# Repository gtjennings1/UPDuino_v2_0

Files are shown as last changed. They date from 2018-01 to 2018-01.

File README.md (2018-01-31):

# UPDuino_v2_0
UPDuino v2.0 - PCB Design Files, Designs, Documentation

UPDuino v2.0 is a small, low cost FPGA board.  
It is the same board as UPDuino v1.0, but v2.0 has a built-in USB programmer
(Similar to Arduino Pro Mini vs Arduino Nano microcontroller boards respectively).

Gnarly Grey UPDuino v2.0 Board Features

    Lattice UltraPlus FPGA
        5.3K LUTs, 1Mb SPRAM, 120Kb DPRAM, 8 Multipliers
        
    FTDI FT232H USB to SPI Device
    
    34 GPIO on 0.1” headers
    
    SPI Flash, RGB LED, 3.3V and 1.2V Regulators
    
    Open source schematic and layout using free Eagle PCB design tools
        Download Schematic & Layout
        Schematic PDF
        Programming Instructions
        RGB LED Example Project

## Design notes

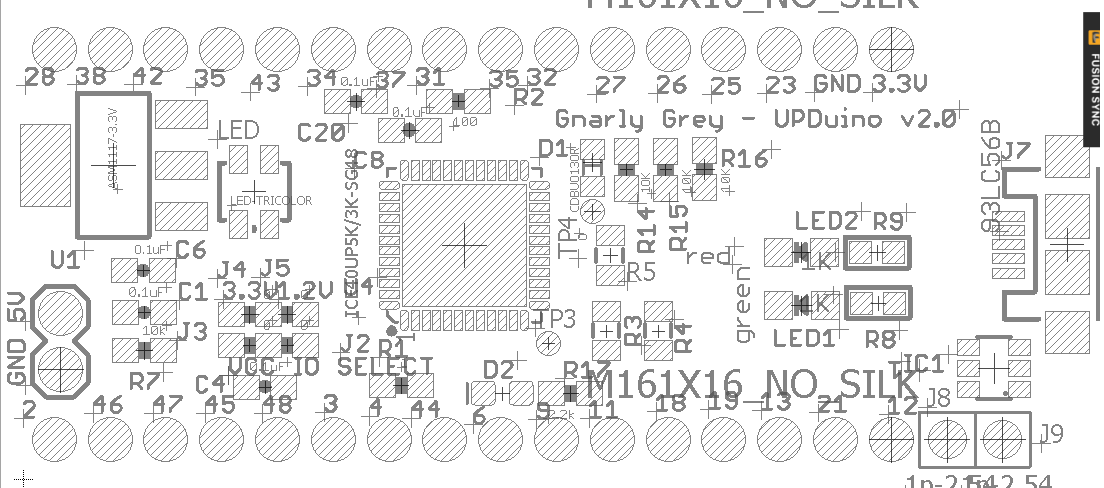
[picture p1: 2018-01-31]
PCB/top_orientation.png

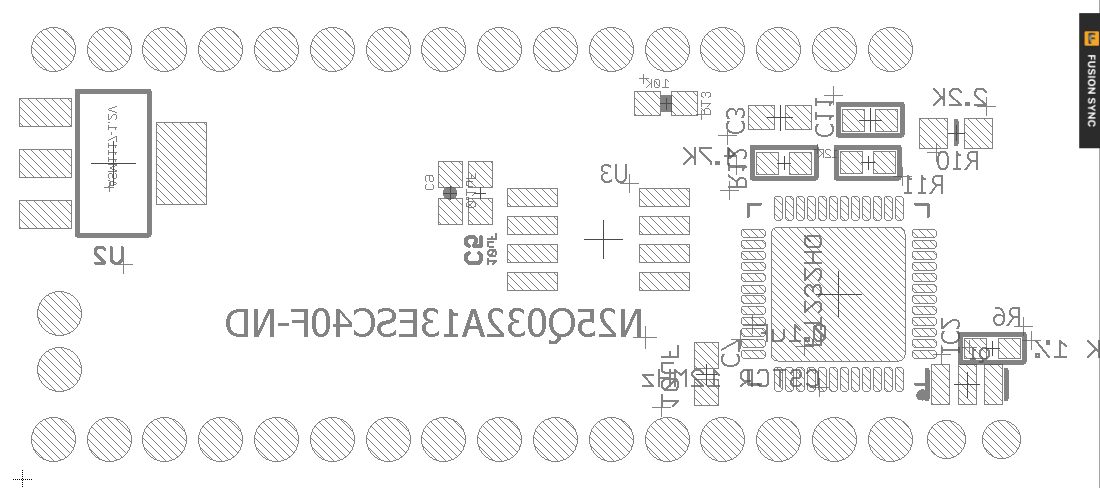
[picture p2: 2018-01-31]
PCB/bot_orientation.png

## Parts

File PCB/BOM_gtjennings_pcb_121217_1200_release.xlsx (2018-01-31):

EXAMPLE BILL OF MATERIALS (BOM)
Place your mouse over the red comment markers in the top right corner of the cells in the row below to see more info on the data in that column
1 | 2 | 3 | 4 | 5 | 6 | 7 | 8 | 9 | 10 | 11
Sequential Item Nos | Consolidated quantity of each Part No | Component ID's separated by Commas | Confirmation Yes or No Parts are fitted this Build (Note 1) | Full Description of Part e.g. for capacitor include value, tolerance and type or Dielectric | Value or Type No | Case Style | Supplier or Manufacturer (Note 2) | Supplier Stock No or Manufacturer's Part No (Note 2) | Side of Board Mounted | PTH or SMT
Item | Qty | Reference | Fit | Part Description | Value | Package | Supplier | Supplier Ref | Side | Mount Type
1 | 6 | C1,C3,C6,C8,C11,C20,C9 | Y | Capacitors | 0.1uF | 0603-CAP |  |  |  | S
2 | 1 | C7,C5 | y | Capacitors | 10uF | 0603-CAP
3 | 1 | D1 | Y | Diode | CDBU0130R | SOD523 |  |  |  | S
4 | 1 | D2 | Y | GREEN LED_0603 | APT1608SGC (https://www.digikey.com/product-detail/en/kingbright/APT1608SGC/754-1121-1-ND/1747838) | 0603_LED
5 | 0 | J6,JP5,JP6 | N | Connectors | DNI | 0603-RES |  |  |  | P
6 | 2 | J3, J4 | Y | Resistors | 0 | 0603-RES
7 | 0 | J2, J5 | N | Resistors | DNI | 0603-RES |  |  |  | S
8 | 1 | J7 | Y | USB connector | USB-MicroB | 10118192-0001LF (https://www.digikey.com/product-detail/en/amphenol-fci/10118192-0001LF/609-4613-1-ND/2785378) |  | 10118192-0001LF (https://www.digikey.com/product-detail/en/amphenol-fci/10118192-0001LF/609-4613-1-ND/2785378)
9 | 1 | LED | Y | LED | LED-TRICOLOR | LED-TRICOLOR-SMD |  | CLV1L-FKB-CHMMQEHBB7673673CT-ND | T | S
10 | 1 | R1 | Y | Resistors | 1 | 0603-RES |  |  |  | S
11 | 2 | R2,R17 | Y | Resistors | 100 | 0603-RES |  |  |  | S
12 | 1 | R3 | Y | Resistors | 0 | 0603-RES |  |  |  | P
13 | 2 | R4,R5 | Y | Resistors | 0 | 0805-RES |  |  |  | P
14 | 1 | R6 | Y | Resistors | 12k 1% | 0603-RES
15 | 5 | R7,R13,R14,R15,R16 | Y | Resistors | 10k | 0603-RES |  |  |  | S
16 | 2 | R8,R9 | Y | Resistors | 1k | 0603-RES
17 | 1 | R10 | Y | Resistors | 2.2k | 0603-RES
18 | 1 | R11 | Y | Resistors | 4.7k | 0603-RES
19 | 1 | R12 | Y | Resistors | 12k | 0603-RES
20 | 1 | U1 | Y | PowerIC | ASM1117-3.3 | SOT223 |  | ASM1117-3.3 | T | S
21 | 1 | U2 | Y | PowerIC | ASM1117-1.2 | SOT223 |  | ASM1117-1.2 | B | S
22 | 1 | U3 | Y | 25Q32 | 25Q32 | SO8 | Winbond Electronics (https://www.digikey.com/en/supplier-centers/w/winbond-electronics) | 25Q32 | B | S
23 | 1 | U4 | Y | ICE40UP5K-3K-SG48 | ICE40UP5K/3K-SG48 | ICE40UP5K/3K-SG48 | Lattice Semiconductor | ICE40UP5K/3K-SG48 | T | S
24 | 1 | IC1 | Y | Memory IC | 93LC56B | SOT23-6
25 | 1 | IC2 | Y | FT232HQ IC | FT232HQ | QFN48_8MM
26 | 1 | Q1 | Y | Resonator_smd | CSTCR 12MHz | CSTCE12M0G55-R0 (https://www.digikey.com/product-detail/en/murata-electronics-north-america/CSTCE12M0G55-R0/490-1197-1-ND/584634)
 | 37

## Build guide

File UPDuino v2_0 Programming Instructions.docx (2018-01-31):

UPDuino v2.0 Device Programming

Hardware Needed:

- Gnarly Grey UPDuino v2.0 Board
  - http://gnarlygrey.atspace.cc/development-platform.html#upduino_v2

Software Needed:

- Lattice Diamond Programmer Standalone (v3.9 x64 used for programming instructions)
  - http://www.latticesemi.com/en/Products/DesignSoftwareAndIP/ProgrammingAndConfigurationSw/Programmer.aspx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
- Lattice iCECube2 Software (
  - http://www.latticesemi.com/Products/DesignSoftwareAndIP/FPGAandLDS/iCEcube2.aspx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

FPGA Projects Needed:

- UPDuino Blinky LED Design
  - http://www.gnarlygrey.com/downloads/RGB_LED_BLINK_20170606.tar

Programming (SPI Flash):

1. Plug UPDuino v2.0 in to your PC using the micro USB port on the board
2. Open Lattice Diamond Programmer
3. Click ‘Detect Cable’ then ‘OK’
4. After scanning select ‘Generic JTAG Device’ and ‘Select iCE40 UltraPlus’
5. Under ‘Device’ click iCE40UP3K and change it to iCE40UP5K
6. Under ‘Operation’ double click ‘Fast Program’ and change ‘Access Mode:’ to ‘SPI Flash Programming’
7. Select your *.hex programming file under ‘Programming file’.
8. Configure the following ‘SPI Flash Options’
  a. Numonyx
  b. SPI-N25Q032
  c. 8-pin VDFPN8
9. Click ‘Load from File’ under ‘SPI Programming’ to get load size
10. Click ‘Design’→’Program’

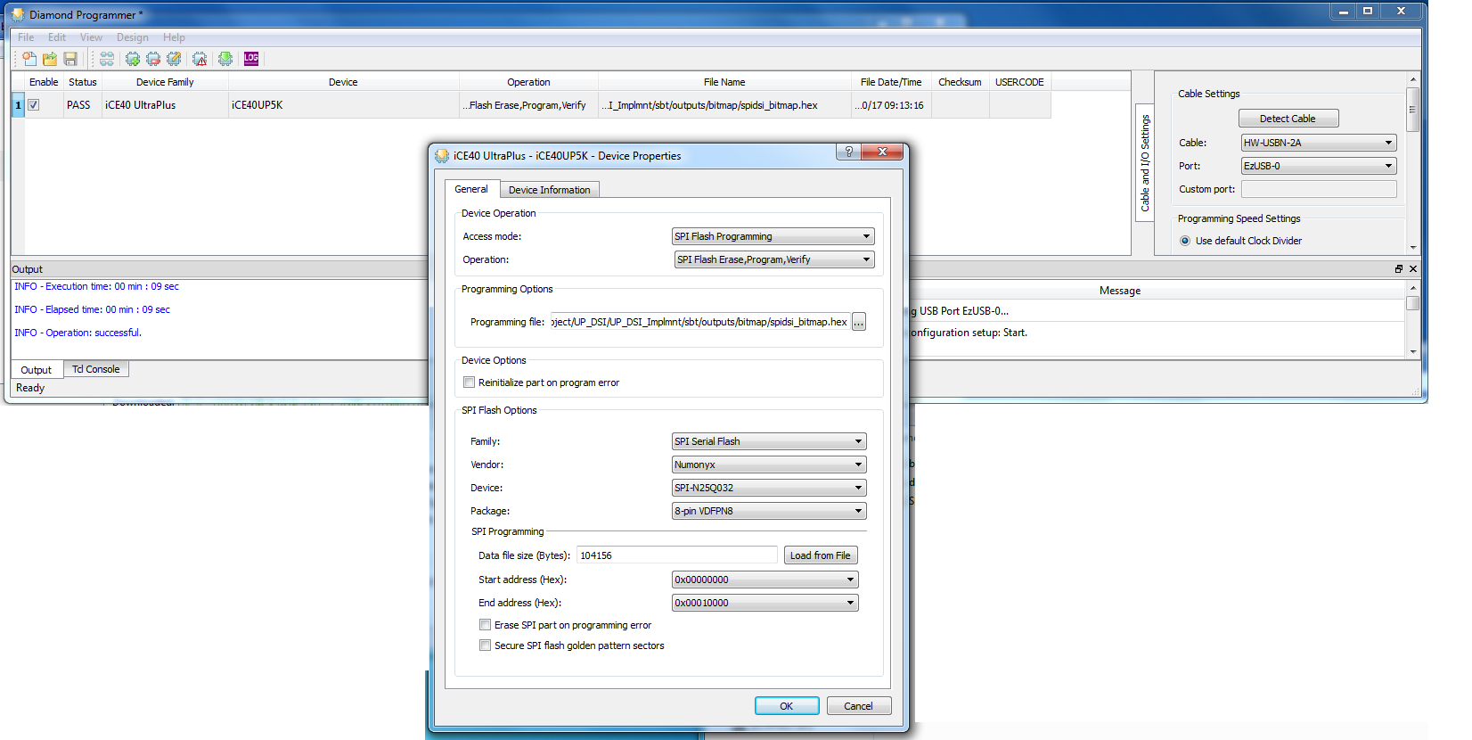
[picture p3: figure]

Project Synthesis (Compiling) and bitstream (Firmware) generation:

1. Unzip RGB_LED_BLINK_20170606.zip
2. Open Lattice iCECube2 Software
3. Double click ‘Open Project’
4. Navigate to *\RGB_LED_BLINK_20170606\rgb\rgb_sbt.project and ‘Open’
5. Double click ‘Run Synplify Pro Synthesis’
6. Right click on ‘Run P&R’ and left click ‘Run Bitmap’
  a. Note – this will run all remaining synthesis steps including place, route and bitmap generation.
  b. Generated bitstream will be loaded in the *\rgb\rgb_Implmnt\sbt\outputs\bitmap folder

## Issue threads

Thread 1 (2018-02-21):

12Mhz clock source from FTDI as external clock for FPGA PLL?

fanoush, 2018-02-21:
Looks like the OSC_OUT from the FTDI goes to J9. Is it supposed to be connected back to FPGA as external clock source for the PLL to get stable clock? Could you perhaps document it  a bit (possibly also with a few verilog lines) how to do it if it is indeed supposed to be used like that? Many thanks.

olofk, 2018-12-03:
I would very much want to know this too. The HFOSC/LFOSC specs states a +-10% accuracy, which is pretty much, and might be problematic even with a simple thing as a UART

fanoush, 2019-03-26:
Just answering myself. I finally tried and it seems to work. I've seen J8 somehow being connected on FPGA [101 board](https://hackaday.io/project/158275-fpga-101-workshop-badge) and examples took 12MHz clock from [pin 35](https://github.com/mmicko/fpga101-workshop/blob/master/projects/galaksija/pinout.pcf).

 I did not find pdf schematics of the board  howeverI connected J8 to pin 35 by wire and modified blinker example and indeed it worked and blinked much slower than with internal 48MHz. I guess pin 35 is chosen as it is [global pin](https://github.com/osresearch/up5k/blob/master/images/pinout.jpg) so the clock can be directly routed to any part of fpga (?)

I also tried to connect it to nearest pin 12 and used is as source for pll and derive 48MHz clock from it and it worked too and blinker example blinked again as with internal 48MHz clock. For that I used output of 'icepll -o 48 -m -f pll.v' command and used pin 12 as clock_in

So I am not sure if this is safe and whether there is some additional setting possible on the input pin so it would not e.g. put extra load on osc_out but it seems to work as is :-)

fanoush, 2019-03-26:
> I did not find pdf schematics

OK I found https://github.com/mmicko/workshop_badge/tree/master/workshop-gerber and uploaded badge.zip to http://www.gerber-viewer.com/ and it seems J8 simply goes to pin 35 so I guess that's it.

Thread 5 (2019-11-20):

Cannot "Detect Cable" in diamond programmer

mattroos, 2019-11-20:
@gtjennings1, I'm using Ubuntu 16.04. I downloaded the Diamond programmer standalone (version 3.11x64 is the only one I've found available on the Lattice website), converted it from RPM to DEB file, and installed it using dpkg.

When I launch the programmer I get a GUI with three radio buttons. The one labeled "Create a new project from a JTAG scan" has below it a "Detect Cable" button, and drop-down lists for "Cable" and "Port". All of this is grayed out, however. The only two radio buttons that are available for selection are "Create a new blank project" and "Open an existing programmer project".

Any advice on how to fix this?

mattroos, 2019-11-21:
Additionally, I tried the suggestions found [here](https://ycnrg.org/lattice-diamond-on-ubuntu-16-04/), to no avail. Also, if I chose the "Create a new blank project" radio button, a new project is created and the GUI changes to one that looks like of the image in the page linked above, with an enabled "Detect Cable" button. But no FTDI USB host chip is detected.

mattroos, 2019-12-18:
I beat my head on this for a while to no avail. I also tried installing Fedora (a Red Hat derivative) and installed the Diamond programmer from the RPM, then again follow suggestions from the link above (which are similar to the installation instructions in the Lattice manual). All for naught.

I've given up, installed Windows 10 instead, and can now successfully complete the tasks in the [programming instructions](https://github.com/gtjennings1/UPDuino_v2_0/blob/master/UPDuino%20v2_0%20Programming%20Instructions.docx).

Closed 2019-12-18.

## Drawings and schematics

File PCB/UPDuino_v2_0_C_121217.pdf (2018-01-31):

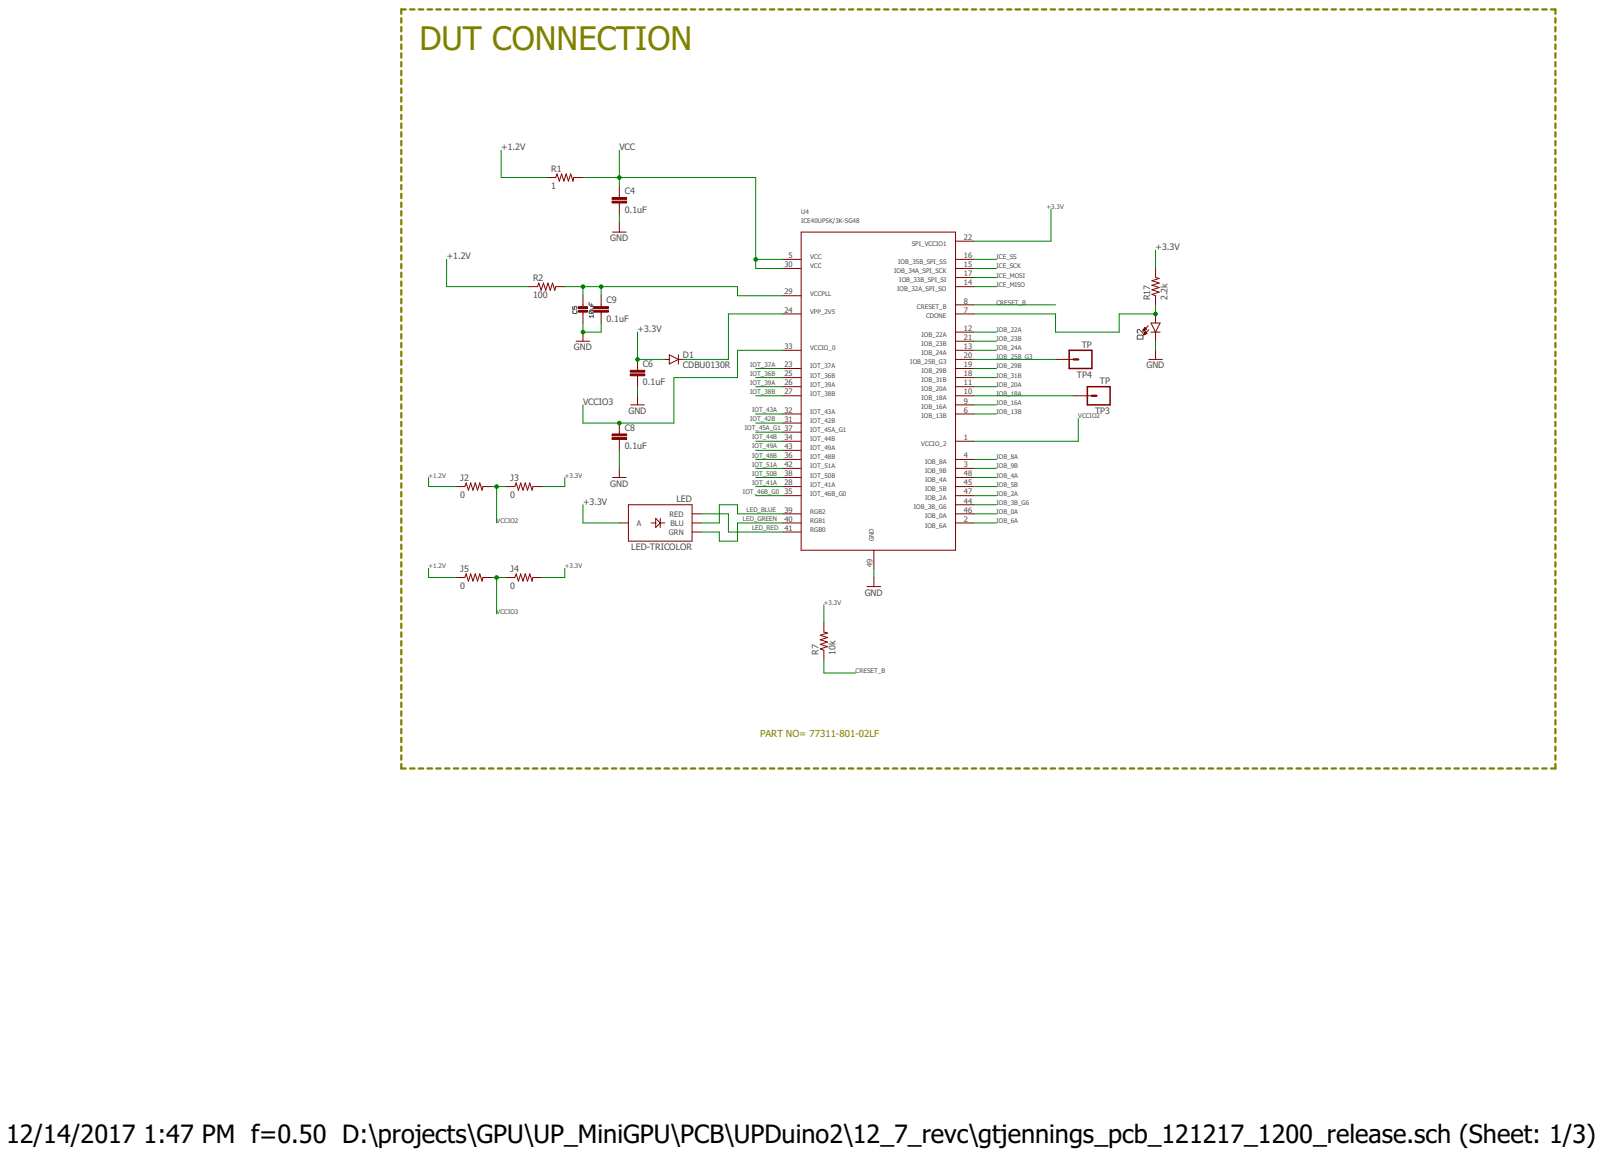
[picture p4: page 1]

12/14/2017 1:47 PM f=0.50 D:\projects\GPU\UP_MiniGPU\PCB\UPDuino2\12_7_revc\gtjennings_pcb_121217_1200_release.sch (Sheet: 1/3)

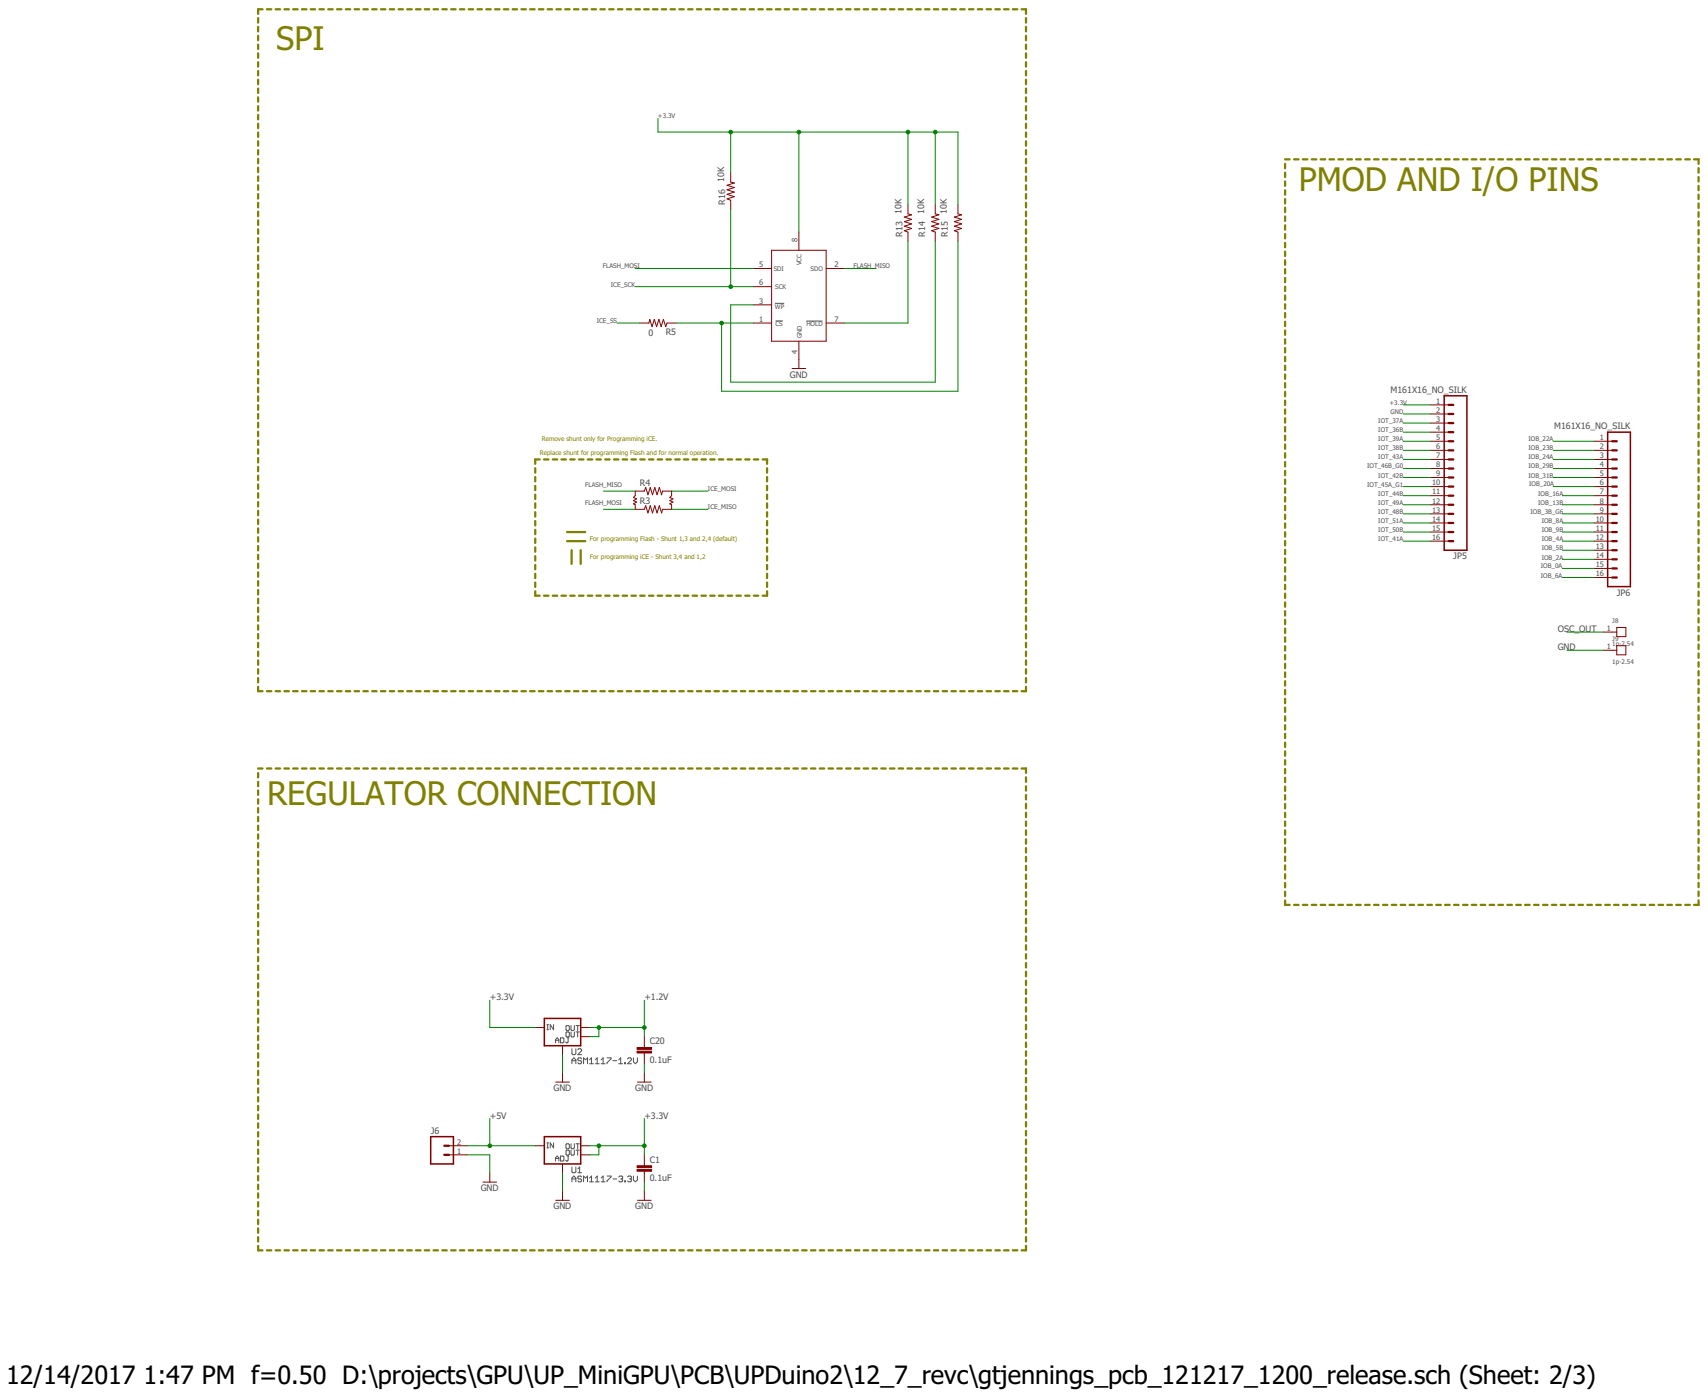
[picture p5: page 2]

Remove shunt only for Programming iCE. Replace shunt for programming Flash and for normal operation.

For programming Flash - Shunt 1,3 and 2,4 (default) For programming iCE - Shunt 3,4 and 1,2

12/14/2017 1:47 PM f=0.50 D:\projects\GPU\UP_MiniGPU\PCB\UPDuino2\12_7_revc\gtjennings_pcb_121217_1200_release.sch (Sheet: 2/3)

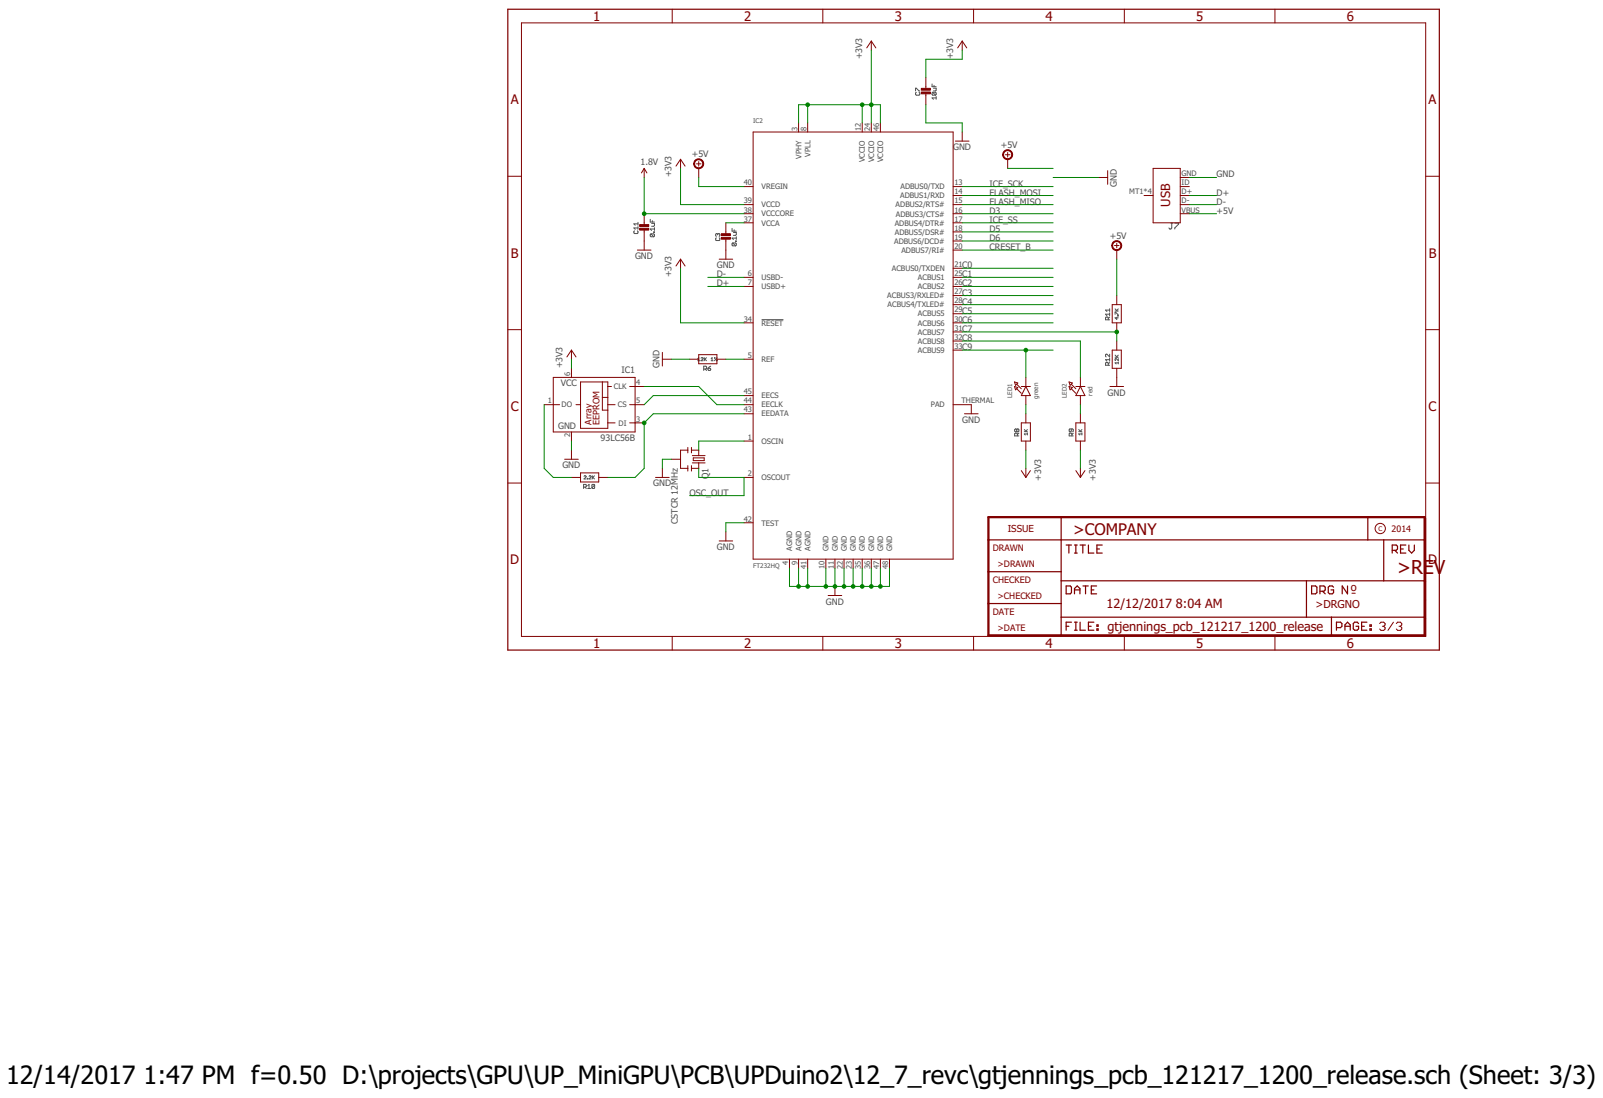
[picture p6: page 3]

12/14/2017 1:47 PM f=0.50 D:\projects\GPU\UP_MiniGPU\PCB\UPDuino2\12_7_revc\gtjennings_pcb_121217_1200_release.sch (Sheet: 3/3)

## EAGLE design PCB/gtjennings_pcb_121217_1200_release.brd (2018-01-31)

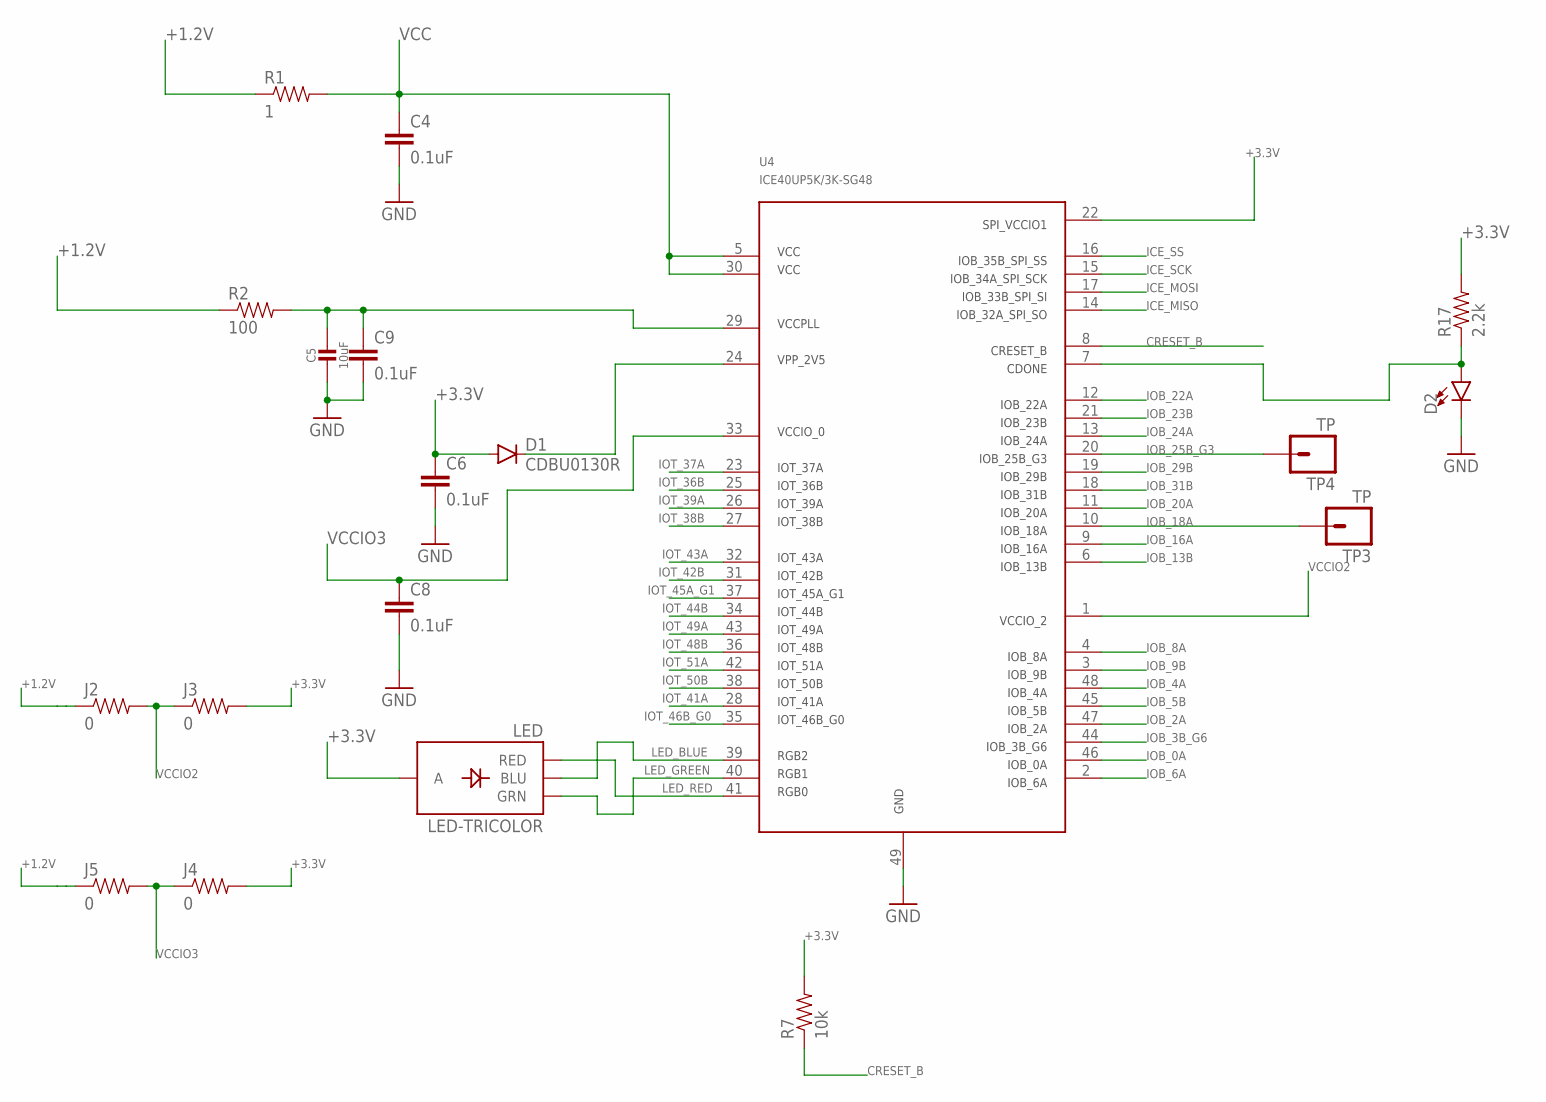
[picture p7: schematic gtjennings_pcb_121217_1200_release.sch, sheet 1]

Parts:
C4, C6, C8, C9: 0.1uF; 0603-CAP
C5: 10uF; 0603-NO
D1: CDBU0130R; SOD523
D2: LED0603; LED-0603
J2, J3, J4, J5: 0; 0603-RES
LED: LED-TRICOLOR; LED-TRICOLOR-SMD
R1: 1; 0603-RES
R2: 100; 0603-RES
R7: 10k; 0603-RES
R17: 2.2k; 0603-RES
TP3, TP4: TP
U4: ICE40UP5K/3K-SG48

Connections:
+1.2V: J2.1, J5.1, R1.1, R2.1; also elsewhere on the board
+3.3V: C6.1, D1.A, J3.2, J4.2, LED.A, R7.2, R17.2, U4.22; also elsewhere on the board
CRESET_B: R7.1, U4.8; also elsewhere on the board
GND: C4.2, C5.2, C6.2, C8.2, C9.2, D2.C, U4.49; also elsewhere on the board
ICE_MISO: U4.14; also elsewhere on the board
ICE_MOSI: U4.17; also elsewhere on the board
ICE_SCK: U4.15; also elsewhere on the board
ICE_SS: U4.16; also elsewhere on the board
IOB_0A: U4.46; also elsewhere on the board
IOB_2A: U4.47; also elsewhere on the board
IOB_3B_G6: U4.44; also elsewhere on the board
IOB_4A: U4.48; also elsewhere on the board
IOB_5B: U4.45; also elsewhere on the board
IOB_6A: U4.2; also elsewhere on the board
IOB_8A: U4.4; also elsewhere on the board
IOB_9B: U4.3; also elsewhere on the board
IOB_13B: U4.6; also elsewhere on the board
IOB_16A: U4.9; also elsewhere on the board
IOB_18A: TP3.1, U4.10
IOB_20A: U4.11; also elsewhere on the board
IOB_22A: U4.12; also elsewhere on the board
IOB_23B: U4.21; also elsewhere on the board
IOB_24A: U4.13; also elsewhere on the board
IOB_25B_G3: TP4.1, U4.20
IOB_29B: U4.19; also elsewhere on the board
IOB_31B: U4.18; also elsewhere on the board
IOT_36B: U4.25; also elsewhere on the board
IOT_37A: U4.23; also elsewhere on the board
IOT_38B: U4.27; also elsewhere on the board
IOT_39A: U4.26; also elsewhere on the board
IOT_41A: U4.28; also elsewhere on the board
IOT_42B: U4.31; also elsewhere on the board
IOT_43A: U4.32; also elsewhere on the board
IOT_44B: U4.34; also elsewhere on the board
IOT_45A_G1: U4.37; also elsewhere on the board
IOT_46B_G0: U4.35; also elsewhere on the board
IOT_48B: U4.36; also elsewhere on the board
IOT_49A: U4.43; also elsewhere on the board
IOT_50B: U4.38; also elsewhere on the board
IOT_51A: U4.42; also elsewhere on the board
LED_BLUE: LED.B (BLU), U4.39
LED_GREEN: LED.G (GRN), U4.40
LED_RED: LED.R (RED), U4.41
unnamed: C5.1, C9.1, R2.2, U4.29
unnamed: D1.C, U4.24
unnamed: D2.A, R17.1, U4.7
VCC: C4.1, R1.2, U4.5, U4.30
VCCIO2: J2.2, J3.1, U4.1
VCCIO3: C8.1, J4.1, J5.2, U4.33

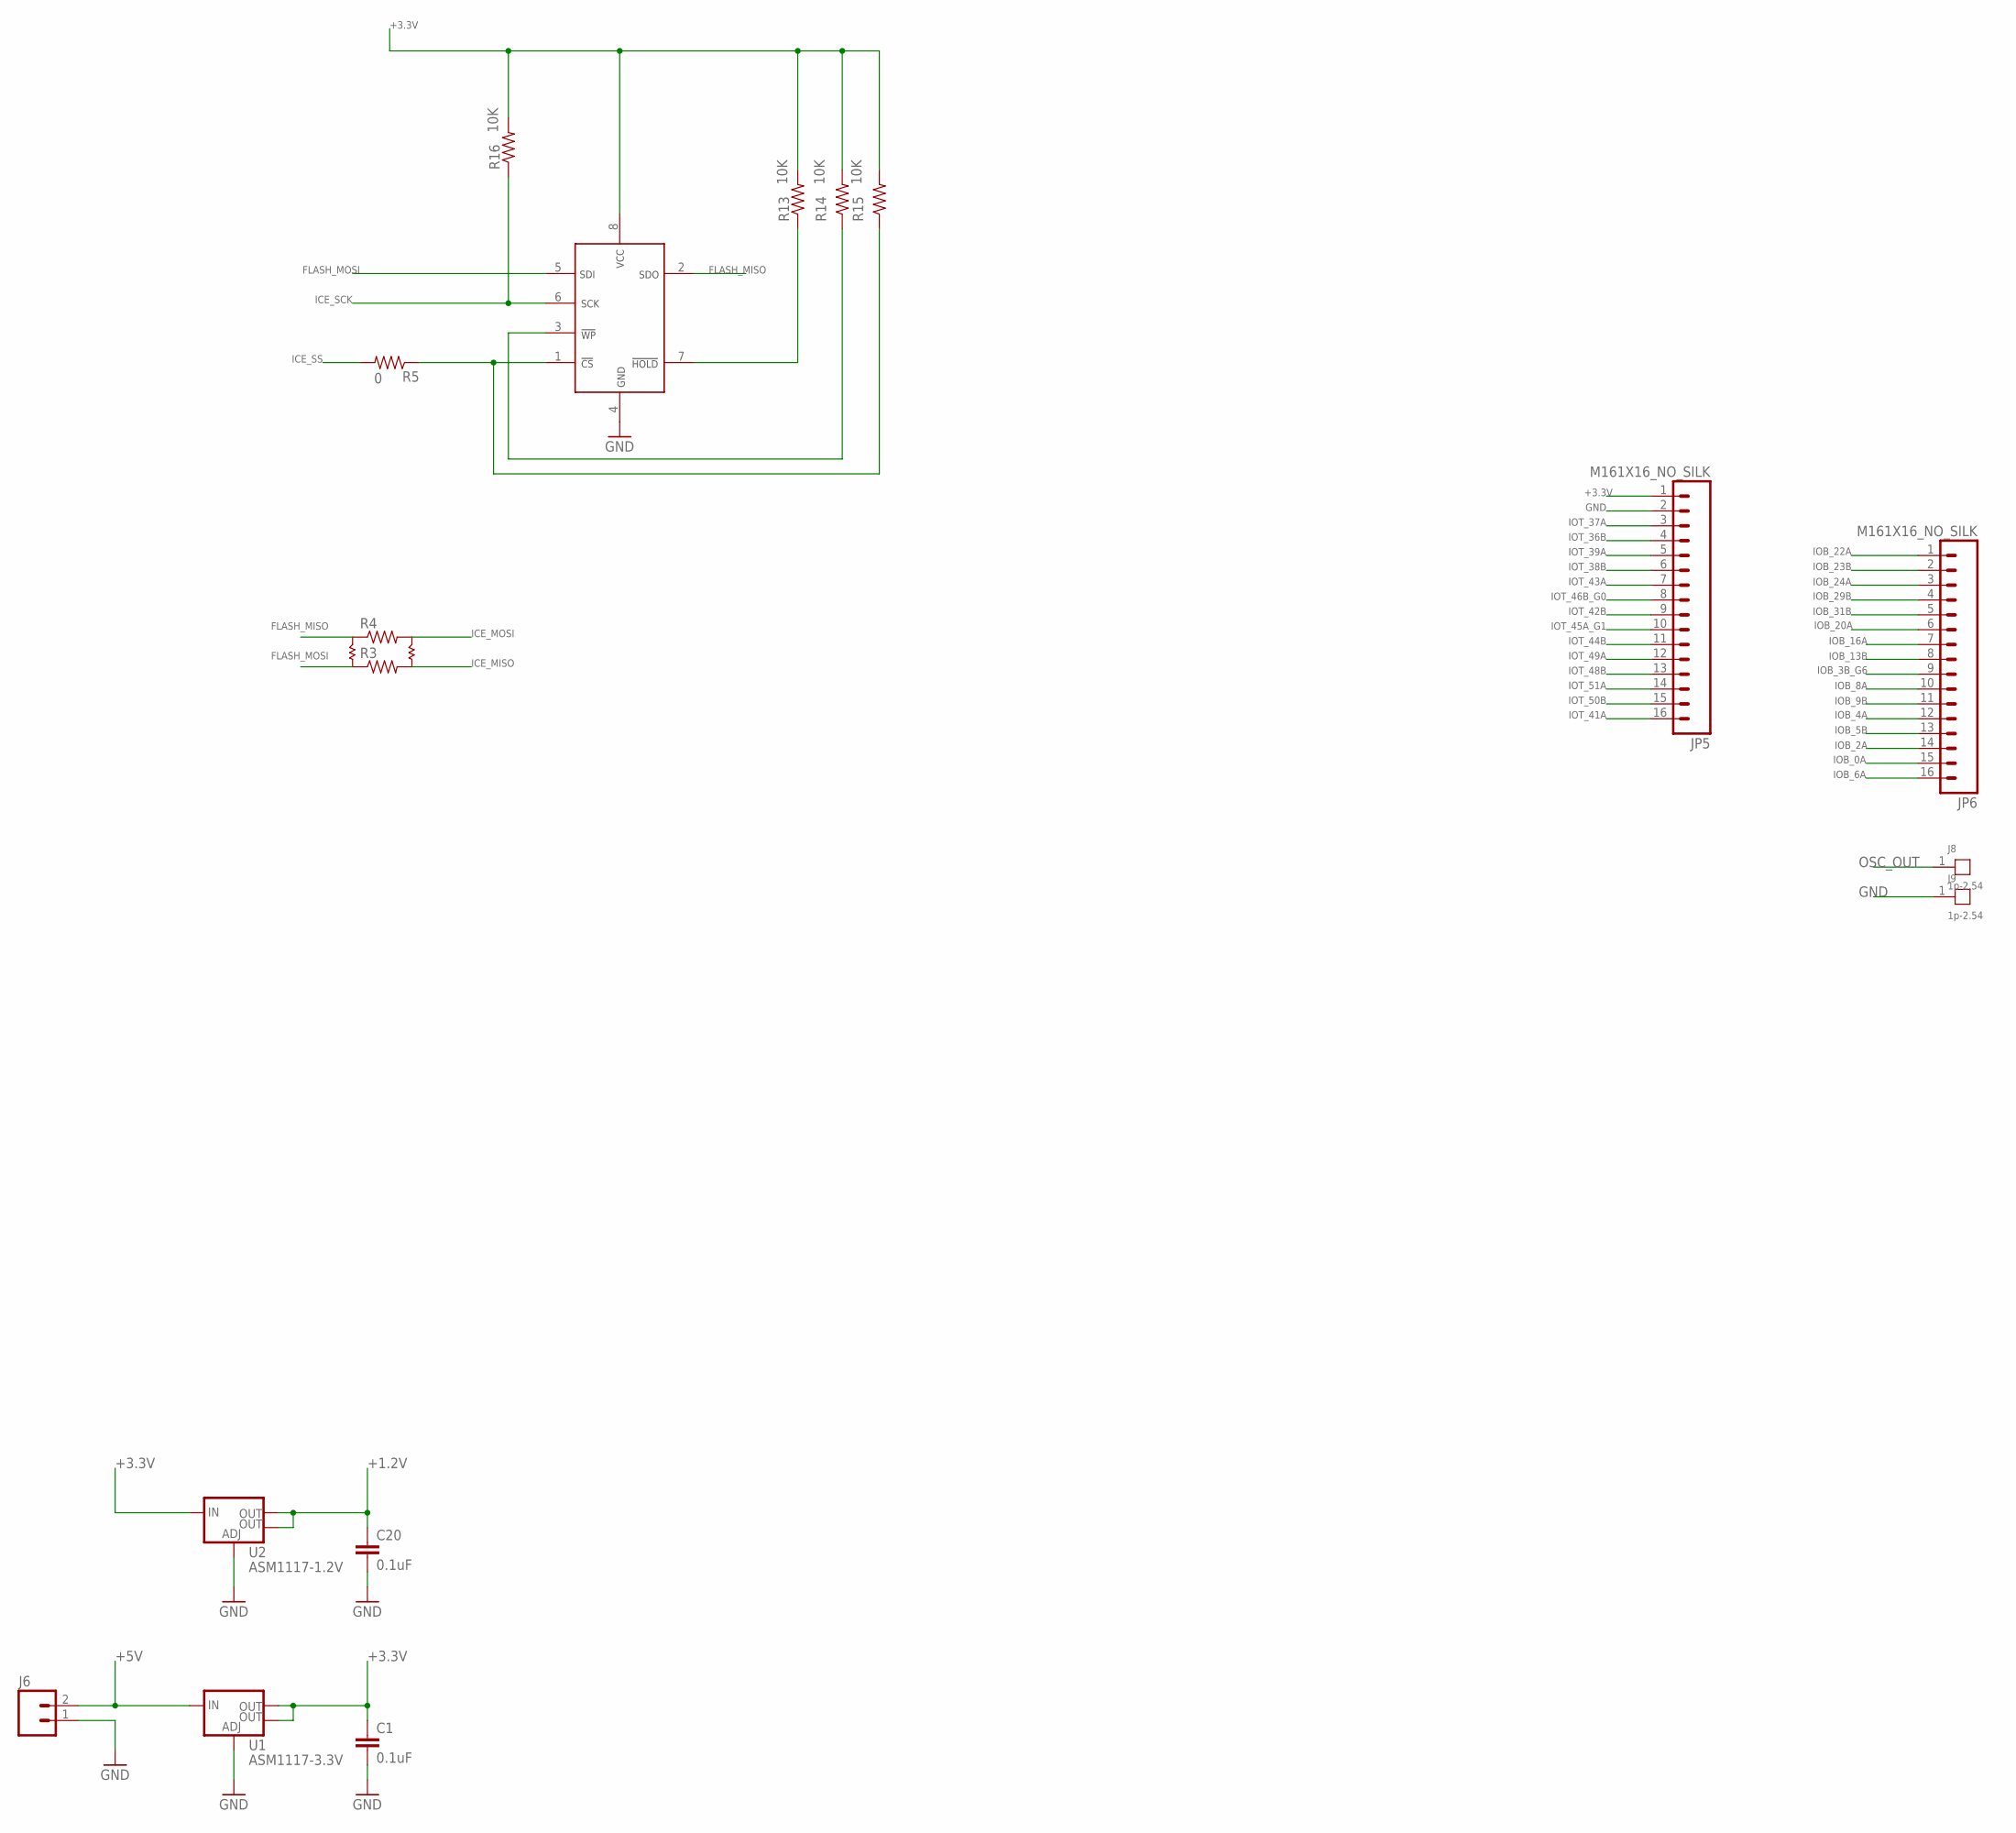
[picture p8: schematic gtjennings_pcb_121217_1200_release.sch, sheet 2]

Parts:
C1, C20: 0.1uF; 0603-CAP
J6: M02PTH; 1X02
J8, J9: 1p-2.54; 1P-65/35MIL
JP5, JP6: M161X16_NO_SILK; 1X16_NO_SILK
R3, R4: RESISTOR0805-RES; 0805
R5: 0; 0805
R13, R14, R15, R16: 10K; 0603-RES
U1: ASM1117-3.3V; SOT223
U2: ASM1117-1.2V; SOT223
U3: N25Q032A13ESC40F-ND; SO8

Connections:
+1.2V: C20.1, U2.2 (OUT), U2.4 (OUT); also elsewhere on the board
+3.3V: C1.1, JP5.1, R13.2, R14.2, R15.2, R16.2, U1.2 (OUT), U1.4 (OUT), U2.3 (IN), U3.8; also elsewhere on the board
+5V: J6.2, U1.3 (IN); also elsewhere on the board
FLASH_MISO: R4.1, U3.2; also elsewhere on the board
FLASH_MOSI: R3.1, U3.5; also elsewhere on the board
GND: C1.2, C20.2, J6.1, J9.1, JP5.2, U1.1 (ADJ), U2.1 (ADJ), U3.4; also elsewhere on the board
ICE_MISO: R3.2; also elsewhere on the board
ICE_MOSI: R4.2; also elsewhere on the board
ICE_SCK: R16.1, U3.6; also elsewhere on the board
ICE_SS: R5.2; also elsewhere on the board
IOB_0A: JP6.15; also elsewhere on the board
IOB_2A: JP6.14; also elsewhere on the board
IOB_3B_G6: JP6.9; also elsewhere on the board
IOB_4A: JP6.12; also elsewhere on the board
IOB_5B: JP6.13; also elsewhere on the board
IOB_6A: JP6.16; also elsewhere on the board
IOB_8A: JP6.10; also elsewhere on the board
IOB_9B: JP6.11; also elsewhere on the board
IOB_13B: JP6.8; also elsewhere on the board
IOB_16A: JP6.7; also elsewhere on the board
IOB_20A: JP6.6; also elsewhere on the board
IOB_22A: JP6.1; also elsewhere on the board
IOB_23B: JP6.2; also elsewhere on the board
IOB_24A: JP6.3; also elsewhere on the board
IOB_29B: JP6.4; also elsewhere on the board
IOB_31B: JP6.5; also elsewhere on the board
IOT_36B: JP5.4; also elsewhere on the board
IOT_37A: JP5.3; also elsewhere on the board
IOT_38B: JP5.6; also elsewhere on the board
IOT_39A: JP5.5; also elsewhere on the board
IOT_41A: JP5.16; also elsewhere on the board
IOT_42B: JP5.9; also elsewhere on the board
IOT_43A: JP5.7; also elsewhere on the board
IOT_44B: JP5.11; also elsewhere on the board
IOT_45A_G1: JP5.10; also elsewhere on the board
IOT_46B_G0: JP5.8; also elsewhere on the board
IOT_48B: JP5.13; also elsewhere on the board
IOT_49A: JP5.12; also elsewhere on the board
IOT_50B: JP5.15; also elsewhere on the board
IOT_51A: JP5.14; also elsewhere on the board
unnamed: R13.1, U3.7
unnamed: R14.1, U3.3
unnamed: R5.1, R15.1, U3.1
OSC_OUT: J8.1; also elsewhere on the board

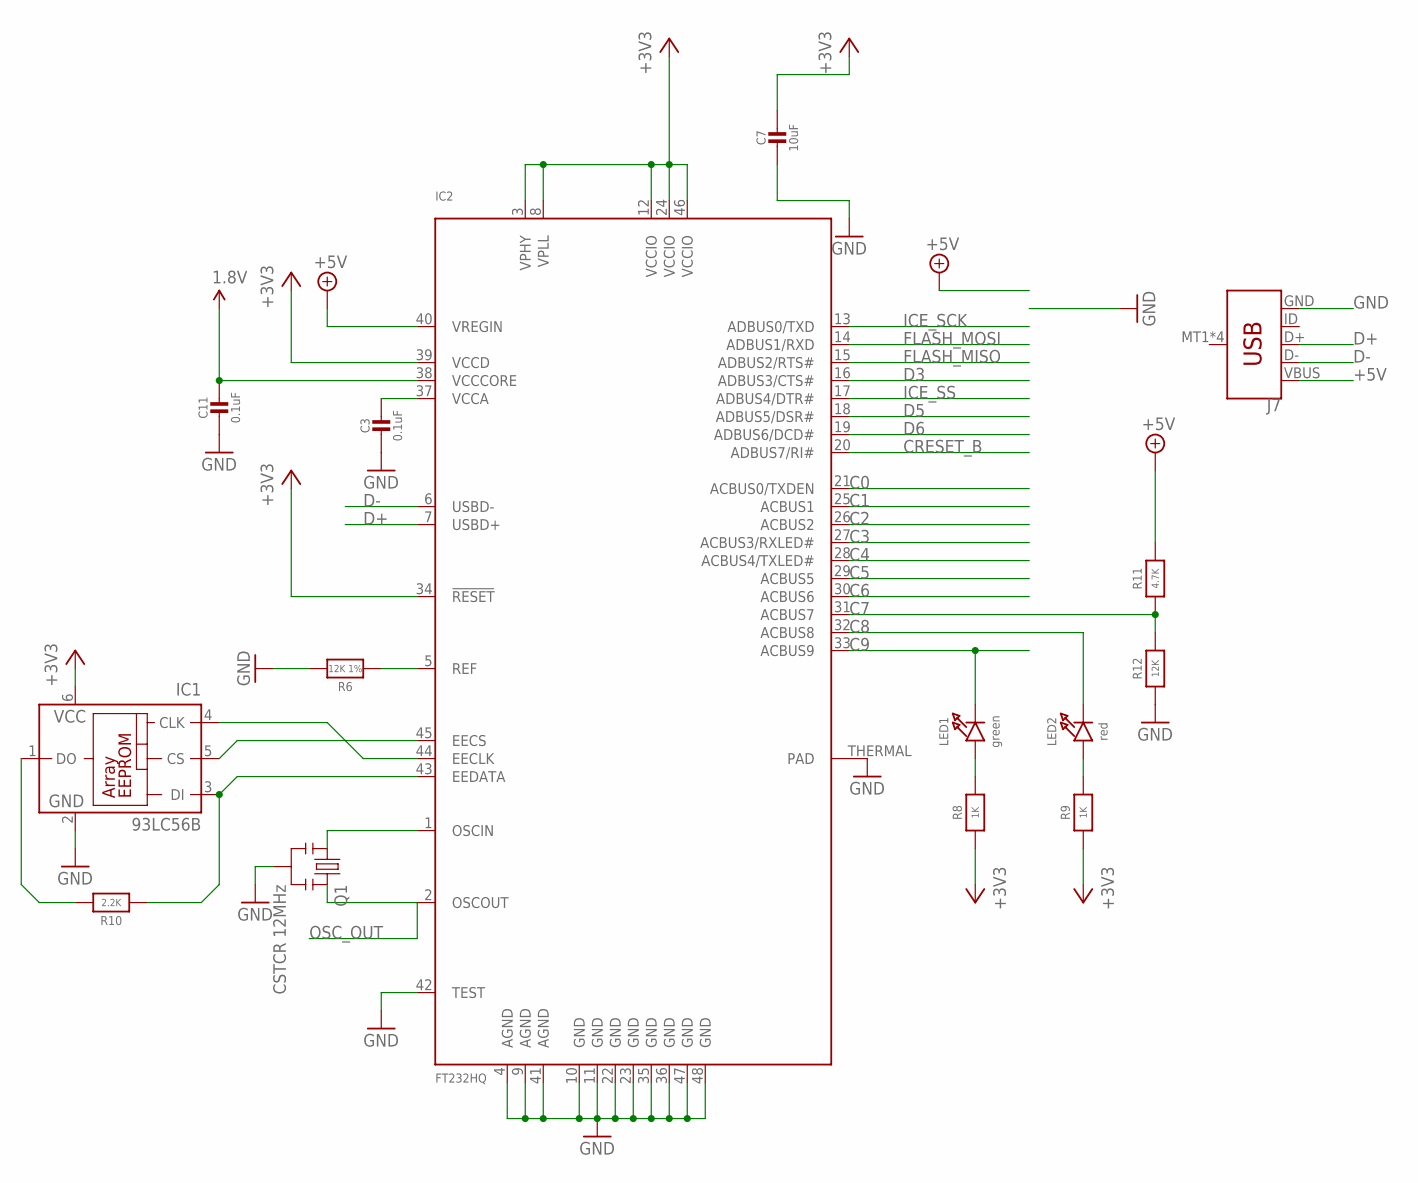
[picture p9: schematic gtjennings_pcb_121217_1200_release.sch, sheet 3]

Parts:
C3: 0.1uF; 0603-NO
C7: 10uF; 0603-NO
C11: 0.1uF; 0603-MINI
IC1: 93LC56B; SOT23-6
IC2: FT232HQ; QFN48_8MM
J7: USB_MICRO-B_SMT; USB-MICROB
LED1: green; CHIPLED_0805_NOOUTLINE
LED2: red; CHIPLED_0805_NOOUTLINE
Q1: CSTCR 12MHz; RESONATOR-SMD
R6: 12K 1%; _0603
R8, R9: 1K; 0603-MINI
R10: 2.2K; _0805MP
R11: 4.7K; 0603-MINI
R12: 12K; 0603-MINI

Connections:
1.8V: C11.1, IC2.38 (VCCCORE)
+3V3: C7.1, IC1.6 (VCC), IC2.3 (VPHY), IC2.8 (VPLL), IC2.12 (VCCIO), IC2.24 (VCCIO), IC2.34 (!RESET), IC2.39 (VCCD), IC2.46 (VCCIO), R8.1, R9.1
+5V: IC2.40 (VREGIN), J7.VBUS, R11.2; also elsewhere on the board
C0: IC2.21 (ACBUS0/TXDEN)
C1: IC2.25 (ACBUS1)
C2: IC2.26 (ACBUS2)
C3: IC2.27 (ACBUS3/RXLED#)
C4: IC2.28 (ACBUS4/TXLED#)
C5: IC2.29 (ACBUS5)
C6: IC2.30 (ACBUS6)
C7: IC2.31 (ACBUS7), R11.1, R12.2
C8: IC2.32 (ACBUS8), LED2.C
C9: IC2.33 (ACBUS9), LED1.C
CRESET_B: IC2.20 (ADBUS7/RI#); also elsewhere on the board
D3: IC2.16 (ADBUS3/CTS#)
D5: IC2.18 (ADBUS5/DSR#)
D6: IC2.19 (ADBUS6/DCD#)
D+: IC2.7 (USBD+), J7.D+
D-: IC2.6 (USBD-), J7.D-
FLASH_MISO: IC2.15 (ADBUS2/RTS#); also elsewhere on the board
FLASH_MOSI: IC2.14 (ADBUS1/RXD); also elsewhere on the board
GND: C3.2, C7.2, C11.2, IC1.2 (GND), IC2.4 (AGND), IC2.9 (AGND), IC2.10 (GND), IC2.11 (GND), IC2.22 (GND), IC2.23 (GND), IC2.35 (GND), IC2.36 (GND), IC2.41 (AGND), IC2.42 (TEST), IC2.47 (GND), IC2.48 (GND), IC2.THERMAL (PAD), J7.GND, Q1.2, R6.2, R12.1; also elsewhere on the board
ICE_SCK: IC2.13 (ADBUS0/TXD); also elsewhere on the board
ICE_SS: IC2.17 (ADBUS4/DTR#); also elsewhere on the board
unnamed: IC2.1 (OSCIN), Q1.1
unnamed: IC2.5 (REF), R6.1
unnamed: LED2.A, R9.2
unnamed: LED1.A, R8.2
unnamed: IC1.3 (DI), IC2.43 (EEDATA), R10.1
unnamed: IC1.5 (CS), IC2.45 (EECS)
unnamed: IC1.4 (CLK), IC2.44 (EECLK)
unnamed: IC1.1 (DO), R10.2
OSC_OUT: IC2.2 (OSCOUT), Q1.3; also elsewhere on the board
VCCA: C3.1, IC2.37 (VCCA)

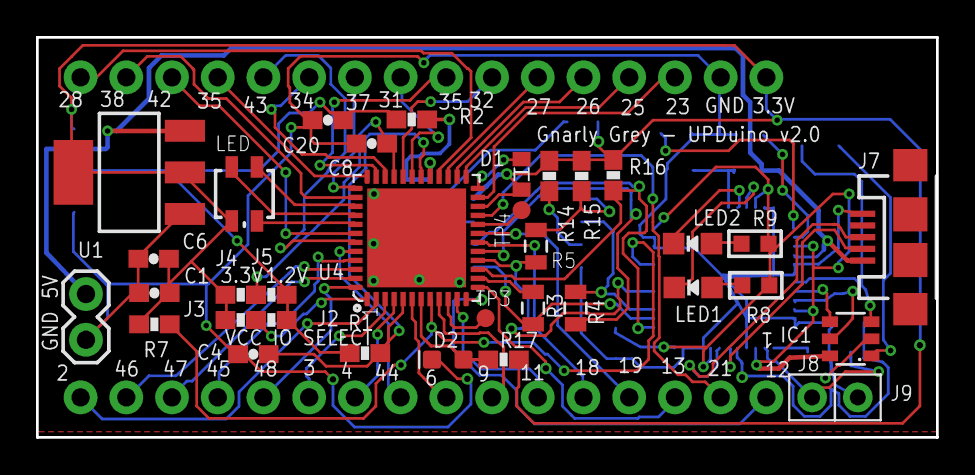
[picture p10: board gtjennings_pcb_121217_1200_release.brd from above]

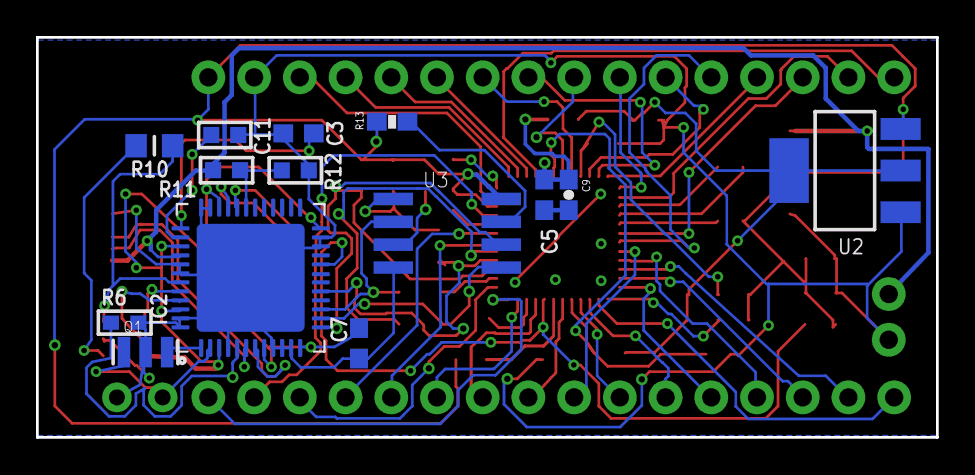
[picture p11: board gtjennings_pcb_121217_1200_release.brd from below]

Board: 2 copper layers, 50.0 x 22.2 mm, 51 parts (14 on the bottom side), 72 nets.

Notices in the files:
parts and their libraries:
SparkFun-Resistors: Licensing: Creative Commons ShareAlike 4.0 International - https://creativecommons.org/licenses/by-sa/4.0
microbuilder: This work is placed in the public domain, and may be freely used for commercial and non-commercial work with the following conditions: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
